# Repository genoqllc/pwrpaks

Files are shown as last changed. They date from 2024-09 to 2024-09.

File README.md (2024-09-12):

# wh3lk submodular power pack

A lil [eurorack power module](https://kicanvas.org/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), primilary for prototyping. Takes 16 pin eurorack power and outputs:

- +12V
- +5V
- +3.3V
- +3.3VA (filtered for analog devices)
- -12V
- -10V reference
- GND



## Releases

Upon merging to `main` and creating a release, the [`Makefile.yml` Github Action](https://github.com/genoqllc/wh3lk/actions/workflows/makefile.yml) will build the project and attach the following to the release:

- `wh3lk-$(GIT_TAG).zip` - Gerbers, drill files, DRC report
- `wh3lk-$(GIT_TAG).bom.csv` - A BOM in CSV format, ready for JLCPCB assembly
- `wh3lk-$(GIT_TAG).bom.xml` - Original KiCad XML BOM
- `wh3lk-$(GIT_TAG).pos.csv` - A POS in CSV format, ready for JLCPCB assembly



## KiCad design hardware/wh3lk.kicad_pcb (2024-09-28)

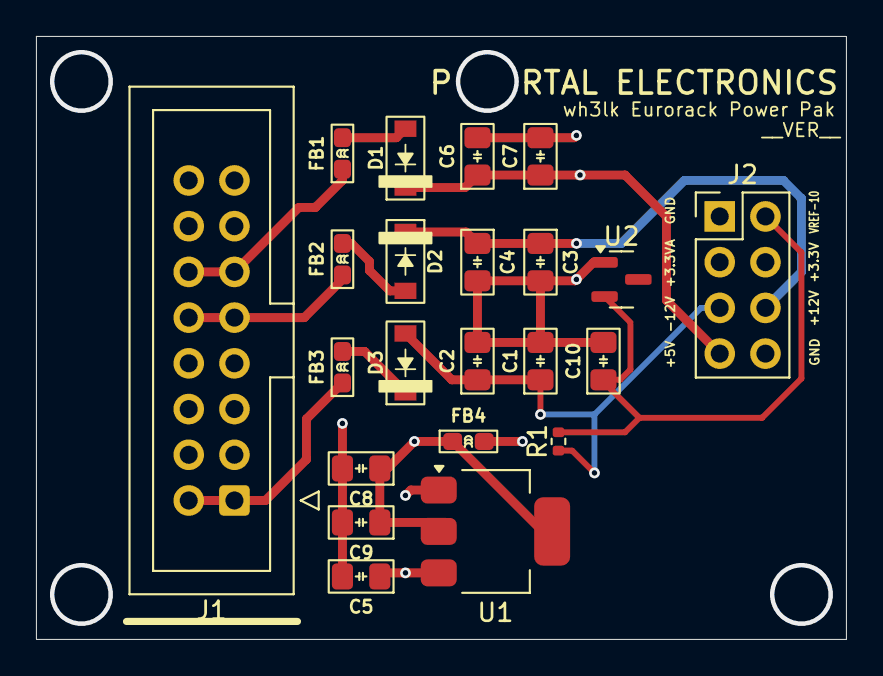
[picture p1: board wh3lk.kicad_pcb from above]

Board: 4 copper layers, 45.0 x 33.5 mm, 22 parts (0 on the bottom side), 13 nets.

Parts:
C1, C2, C3, C4, C5, C6, C7, C10: 22uF; C_0805_HandSolder
C8: 10uF; C_0805_HandSolder
C9: 100nF; C_0805_HandSolder
D1, D2, D3: 30V; D_SOD-123
FB1, FB2, FB3, FB4: 600R@100MHz; L_0603_HandSolder
J1: Eurorack_Power; IDC-Header_2x08_P2.54mm_Vertical
J2: Conn_01x08_Pin; PinHeader_2x04_P2.54mm_Vertical
R1: 2k2R; R_0402_1005Metric
U1: LD1117S33TR_SOT223; SOT-223-3_TabPin2
U2: LM4040DBZ-10; SOT-23

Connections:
+3.3V: C8.1, C9.1, FB4.1, J2.4, U1.2 (VO)
+3.3VA: FB4.2, J2.3
+5V: C5.1, C6.1, C7.1, D1.1 (K), J2.7, U1.3 (VI)
+12V: C3.1, C4.1, D2.1 (K), J2.6
-12V: C1.1, C2.1, D3.2 (A), J2.5, R1.1
GND: C1.2, C2.2, C3.2, C4.2, C5.2, C6.2, C7.2, C8.2, C9.2, C10.2, J1.3 (GND), J1.4 (GND), J1.5 (GND), J1.6 (GND), J1.7 (GND), J1.8 (GND), J2.1, J2.8, U1.1 (GND), U2.1 (K)
unnamed: D1.2 (A), FB1.2
unnamed: D2.2 (A), FB2.2
unnamed: D3.1 (K), FB3.2
RACK+5V: FB1.1, J1.11 (+5V), J1.12
RACK+12V: FB2.1, J1.9 (+12V), J1.10 (+12V)
RACK-12V: FB3.1, J1.1 (-12V), J1.2 (-12V)
VREF-10: C10.1, J2.2, R1.2, U2.2 (A)

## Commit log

2024-09-09 wh3lk: Initial schematic and board (#1)
    * initiall schematic and board
    * Update README.md
    * Corrected resistor package, deleted unused files and gerbers
    * Moved mounting holes to GND
    * bom generation
    * Makefile to export to JCLPCB for fab and assembly
    * Add pos into build:
    * jclpcb wants pos as a csv
    * fix 10uF cap part ref
    * oops added csv here
    [prep.kicad_sch, wh3lk.kicad_pcb, wh3lk.kicad_sch]
2024-09-10 Removed ohm symbol to not break JCLPCB BOM (#3)
    [prep.kicad_sch, wh3lk.kicad_pcb]
2024-09-20 Assign board version via git tag on build (#5)
    [prep.kicad_sch, wh3lk.kicad_pcb, wh3lk.kicad_sch]
2024-09-20 More available, cheaper parts & fix BOM (#6)
    * Change to voltage ref more available at JLCPCB
    * more available, cheaper 10 uF cap
    * prepping to make makefile work with multiple sch
    * cheaper 100 nF cap
    * Generate BOM per sch, then merge
    * remove unused VERSIONED_SCHEMATIC
    * hide some boring ops
    * o ya install rename
    [prep.kicad_sch, wh3lk.kicad_sch]
2024-09-21 Changed 2.2kR resistor to something more available (#7)
    [prep.kicad_sch, wh3lk.kicad_sch]
2024-09-28 Flipped -12V rail b/c I had it wrong
    [prep.kicad_sch, wh3lk.kicad_pcb]
2024-09-28 ok, REALLY fixed the -12v diode
    [wh3lk.kicad_pcb]
